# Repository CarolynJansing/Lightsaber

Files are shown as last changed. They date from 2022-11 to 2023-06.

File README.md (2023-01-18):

# Lightsaber
A lightsaber is a fictional energy sword featured in the Star Wars franchise. This project is a simulation of a lightsaber using LEDs, Sound and an Arduino microcontroller. It is based on the Gyversaber. https://www.instructables.com/Arduino-Based-Lightsaber-With-Light-and-Sound-Effe/

## Files

ArduinoCode : GyverSaber/GyverSaber/Gyversaber.ino

SD Files : GyverSaber/SDsounds

Schemes: PCB/

## Getting Started
These instructions will help you get a copy of the project up and running on your local machine for development and testing purposes.

### Prerequisites
To use this project, you will need the following:

Arduino IDE (https://www.arduino.cc/software)
•	Arduino NANO 
•	Adressable LED stripes WS2811, 12V
•	Button with LED 
•	MPU6050 
•	DF-Player
•	Batteries 18650 with Protection
•	DCDC Step-Down
•	Speaker
•	Resistors
•	Power button
•	Charging port
•	CC CV Charger for 3 cells
•	PCB-Board
•	Blade Pipe
•	PVC Pipes for hilt
•	Wire
•	3D druck
•	Soldering Supplies
I chose to use an PCB aswell you can configure it with my files on JLCPCB

### Installing
Clone the repository to your local machine: git clone https://github.com/CarolynJansing/Lightsaber.git
Open the Arduino IDE and open the Gyversaber.ino file from the cloned repository.
Connect the Arduino microcontroller to your computer using a USB cable.
Select the correct board and port in the Arduino IDE (Tools > Board and Tools > Port).
Upload the code to the Arduino microcontroller.
### Usage
The lightsaber can be controlled by the button. The buttons can be used to turn the lightsaber on and off, change the color of the lightsaber, and change the lightsaber mode.

## Built With
Arduino Nano following the Gyversaber Instructions and changed to a DFPlayer
## Author
Carolyn Jansing - CarolynJansing
+ MadGyver
License
This project is licensed under the MIT License - see the LICENSE file for details.

## Acknowledgments
The Star Wars franchise for inspiration and MadGyver.

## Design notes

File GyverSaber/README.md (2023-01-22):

# This project is based on Gyversaber
 See his inmstructions below

# GyverSaber - Arduino based multicolor sound playing lightsaber
* [Project description](#chapter-0)
* [Folders](#chapter-1)
* [Schemes](#chapter-2)
* [Components](#chapter-3)
* [Assemply and set up](#chapter-7)

## Project description
SUPER-DUPER COOL ARDUINO BASED MULTICOLOR SOUND PLAYING LIGHTSABER!
https://youtu.be/__gp2RfTMnk

## Download last release
[**Click me**](https://github.com/AlexGyver/EnglishProjects/releases/download/GyverSaber/GyverSaber.rar)

#### CAPABILITIES:
* Smooth turning on/off with lightsaber-like sound effect
* Randomly pulsing color (you can turn it off)
* Sounds:
  + MODE 1: generated hum. Frequency depends on angle velocity of blade
  + MODE 2: hum sound from SD card
    - Slow swing - long hum sound (randomly from 4 sounds)
    - Fast swing - short hum sound (randomly from 5 sounds)
* Bright white flash when hitting
* Play one of 16 hit sounds, when hit
  + Weak hit - short sound
  + Hard hit - long "bzzzghghhdh" sound
* After power on blade shows current battery level from 0 to 100 percent
* Battery safe mode:
  + Battery is drain BEFORE TURNING ON: GyverSaber will not turn on, button LED will PULSE a couple of times
  + Battery is drain AFTER TURNING ON: GyverSaber will be turned off automatically
#### CONTROL BUTTON:
* HOLD - turn on / turn off GyverSaber
* TRIPLE CLICK - change color (red - green - blue - yellow - pink - ice blue)
* QUINARY CLICK - change sound mode (hum generation - hum playing)
* Selected color and sound mode stored in EEPROM (non-volatile memory)

## Folders
- **libraries** - libraries
- **GyverSaber** - arduino sketch
- **SDsounds** - GyverSaber sound pack

## Schemes
SCHEME
SCHEME
SCHEME

## Components
* Arduino NANO https://ali.ski/jmFH9_ https://ali.ski/5OBVTQ
* Addressable LED strip. WS2811, 12V. Take **white PCB, IP30, 60 LEDs per meter**
https://ali.ski/NMjk8 https://ali.ski/zW95D
* Button with LED. **Take 5V version** https://ali.ski/Mwcxt
* MPU6050 https://ali.ski/v5KZLL https://ali.ski/uXu5vi
* Cheap MicroSD https://ali.ski/GxgI4D
* MicroSD module mini https://ali.ski/JHIePz https://ali.ski/KsPKO
* Or this https://ali.ski/WKZdDk
* Batteries 18650 with protection https://ali.ski/XBqThJ https://ali.ski/lx5do https://ali.ski/3DZON9
* DCDC Step Down https://ali.ski/Gu17D https://ali.ski/LGc7S https://ali.ski/AZ7FEd
* Amplifier https://ali.ski/w3a6s https://ali.ski/UJQHAm https://ali.ski/9chyq
* Speaker https://ali.ski/fkf3b5 https://ali.ski/f3bznw https://ali.ski/NGb4L
* Resistors KIT https://ali.ski/DsRXU https://ali.ski/0QeVi
* Power button https://ali.ski/ADn0zC
* Charging port https://ali.ski/-02oW https://ali.ski/-gRAOg
* CC CV charger for 3 cells https://ali.ski/uPeDvv https://ali.ski/QY79Lj https://ali.ski/xxHSRf
* Prototype board https://ali.ski/XTO9n

## Assembly and set up
* [Quick start with Arduino](https://learn.sparkfun.com/tutorials/installing-arduino-ide)
* Open GyverSaber.ino and tune:
  - Number of microcircuits WS2811 on LED strip (note: one WS2811 controls 3 LEDs!)
  - Turn on or turn off blade pulsation
  - Hardly recommend measure real resistance of voltage divider resistors
    + System can work without battery monitoring, just deactivate BATTERY_SAFE. **BUT IT IS NOT RECOMMENDED**
* Flash arduino
* MicroSD info:
  - Size < 4G
  - Format to FAT
  - Copy audiofiles **in the root**
  - If you want add your own sounds, convert them to .WAV:
    + 8 bit
	+ 16-32 kHz
	+ Mono
	+ Use online converters or Total Audio Converter
* Assemble schmeme
  - **WARNING!** If you are flashing **assembled scheme**, you must power up it! Arduino will not work correct with connected DCDC converter!
* Enjoy!

## GyverSaber settings
    NUM_LEDS 30         // number of microcircuits WS2811 on LED strip (note: one WS2811 controls 3 LEDs!)
    BTN_TIMEOUT 800     // button hold delay, ms
    BRIGHTNESS 255      // max LED brightness (0 - 255)

    SWING_TIMEOUT 500   // timeout between swings
    SWING_L_THR 150     // swing angle speed threshold
    SWING_THR 300       // fast swing angle speed threshold
    STRIKE_THR 150      // hit acceleration threshold
    STRIKE_S_THR 320    // hard hit acceleration threshold
    FLASH_DELAY 80      // flash time while hit

    PULSE_ALLOW 1       // blade pulsation (1 - allow, 0 - disallow)
    PULSE_AMPL 20       // pulse amplitude
    PULSE_DELAY 30      // delay between pulses

    R1 100000           // voltage divider real resistance
    R2 51000            // voltage divider real resistance
    BATTERY_SAFE 1      // battery monitoring (1 - allow, 0 - disallow)

    DEBUG 0             // debug information in Serial (1 - allow, 0 - disallow)

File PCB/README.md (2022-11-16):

Project files fro KiCad.

Created and designed by @simonmicro with :hearts: 2022

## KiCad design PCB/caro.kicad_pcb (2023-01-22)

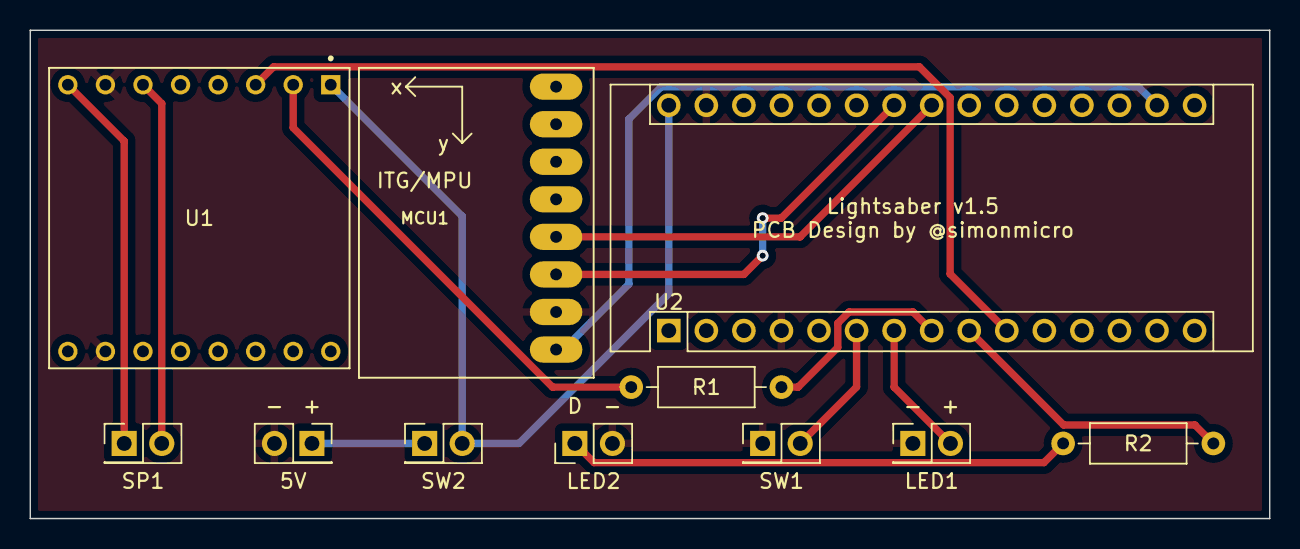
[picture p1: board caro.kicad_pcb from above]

Board: 2 copper layers, 83.8 x 33.0 mm, 11 parts (0 on the bottom side), 15 nets.

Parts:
5V: PinSocket_2x01_P2.54mm_Vertical
LED1: Control Button LED; PinHeader_2x01_P2.54mm_Vertical
LED2: WS2811; PinHeader_1x02_P2.54mm_Vertical
MCU1: GY-521
R1, R2: 1000Ohm; R_Axial_DIN0207_L6.3mm_D2.5mm_P10.16mm_Horizontal
SP1: Speaker; PinHeader_2x01_P2.54mm_Vertical
SW1: Control Button; PinHeader_2x01_P2.54mm_Vertical
SW2: Power Switch; PinHeader_2x01_P2.54mm_Vertical
U1: DFR0299; MODULE_DFR0299
U2: Arduino_Nano_v3.x; Arduino_Nano

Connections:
3.3V: MCU1.1 (VCC), U2.17 (3V3)
5V: SW2.2 (B), U1.1 (VCC), U2.30 (VIN)
+5V: 5V.1, SW2.1 (A)
A4: MCU1.4 (SDA), U2.23 (A4)
A5: MCU1.3 (SCL), U2.24 (A5)
D3: SW1.1, U2.6 (D3)
D4: LED1.2 (A), U2.7 (D4)
D5: R1.1, U2.8 (D5)
D6: R2.1, U2.9 (D6)
D7: U1.3 (TX), U2.10 (D7)
GND: 5V.2, LED1.1 (K), LED2.2 (OUTG), MCU1.2 (GND), SW1.2, U1.7 (GND), U1.10 (GND), U2.4 (GND), U2.29 (GND)
unnamed: R1.2, U1.2 (RX)
unnamed: LED2.1 (OUTR), R2.2
unnamed: SP1.1, U1.8 (SPK2)
unnamed: SP1.2, U1.6 (SPK1)

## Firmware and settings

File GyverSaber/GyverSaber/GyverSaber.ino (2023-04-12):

/*
  ARDUINO BASED MULTICOLOR SOUND PLAYING LIGHTSABER!
    HARDWARE:
      Addressable LED strip (WS2811) to get any blade color and smooth turn on effect
      DFPlaye module to play some sounds
      IMU MPU6050 (accel + gyro) to play sound matching to the swings
    CAPABILITIES:
      Smooth turning on/off with lightsaber-like sound effect
      Randomly pulsing color (you can turn it off)
      Sounds:
        MODE 1: generated hum. Frequency depends on angle velocity of blade
        MODE 2: hum sound from SD card
          Slow swing - long hum sound (randomly from 4 sounds)
          Fast swing - short hum sound (randomly from 5 sounds)
      Bright white flash when hitting
      Play one of 16 hit sounds, when hit
        Weak hit - short sound
        Hard hit - long "bzzzghghhdh" sound
      After power on blade shows current battery level from 0 to 100 percent
      Battery safe mode:
        Battery is drain BEFORE TURNING ON: GyverSaber will not turn on, button LED will PULSE a couple of times
        Battery is drain AFTER TURNING ON: GyverSaber will be turned off automatically
      CONTROL BUTTON:
        HOLD - turn on / turn off GyverSaber
        TRIPLE CLICK - change color (red - green - blue - yellow - pink - ice blue)
        QUARTER CLICK- flame blade mode inspired by Touhou Tenshi Hinanawi
        QUINARY CLICK - change sound mode (hum generation - hum playing)
        Selected color and sound mode stored in EEPROM (non-volatile memory)
*/

// ---------------------------- SETTINGS -------------------------------
#define NUM_LEDS 40         // number of microcircuits WS2811 on LED strip (note: one WS2811 controls 3 LEDs!)
#define BTN_TIMEOUT 1200    // button hold delay, ms
#define BTN_HOLD_TIME 2000  // button hold delay, ms
#define BRIGHTNESS 255      // max LED brightness (0 - 255)

#define SWING_TIMEOUT 500  // timeout between swings
#define SWING_L_THR 150    // swing angle speed threshold
#define SWING_THR 300      // fast swing angle speed threshold
#define STRIKE_THR 150     // hit acceleration threshold
#define STRIKE_S_THR 320   // hard hit acceleration threshold
#define FLASH_DELAY 80     // flash time while hit

#define PULSE_ALLOW 1   // blade pulsation (1 - allow, 0 - disallow)
#define PULSE_AMPL 20   // pulse amplitude
#define PULSE_DELAY 30  // delay between pulses

#define BATTERY_SAFE 0  // battery monitoring (1 - allow, 0 - disallow)

#define DEBUG 1  // debug information in Serial (1 - allow, 0 - disallow)
// ---------------------------- SETTINGS -------------------------------

#define LED_PIN 2
#define BTN 13
#define BTN_LED 0 // -1 -> disable, 4 original
#define SD_ChipSelectPin 10

// -------------------------- LIBS ---------------------------
#include <avr/pgmspace.h>  // PROGMEM library
// #include <TMRpcm.h>  // audio from SD library
#include "Wire.h"
#include "I2Cdev.h"
#include "MPU6050.h"
#include <toneAC.h>   // hum generation library
#include "FastLED.h"  // addressable LED library
#include <EEPROM.h>
#include "Arduino.h"
#include "SoftwareSerial.h"
#include "DFRobotDFPlayerMini.h"

// TMRpcm tmrpcm;
MPU6050 accelgyro;
SoftwareSerial mySoftwareSerial(14, 12);  // RX, TX

DFRobotDFPlayerMini myDFPlayer;
void printDetail(uint8_t type, int value);

CRGB leds[NUM_LEDS];

// -------------------------- LIBS ---------------------------

// ------------------------------ VARIABLES ---------------------------------

int16_t ax, ay, az;
int16_t gx, gy, gz;
unsigned long ACC, GYR, COMPL;
int gyroX, gyroY, gyroZ, accelX, accelY, accelZ, freq, freq_f = 20;
float k = 0.2;
unsigned long humTimer = -9000, mpuTimer, nowTimer;
int stopTimer;
boolean bzzz_flag, ls_chg_state, ls_state;
unsigned long PULSE_timer, swing_timer, swing_timeout, battery_timer, bzzTimer;
byte nowNumber;
byte LEDcolor;  // 0 - red, 1 - green, 2 - blue, 3 - pink, 4 - yellow, 5 - ice blue
byte nowColor, red, green, blue, redOffset, greenOffset, blueOffset;
boolean eeprom_flag, swing_flag, swing_allow, strike_flag, HUMmode;
float voltage;
int PULSEOffset;
boolean tenshiMode;
// ------------------------------ VARIABLES ---------------------------------

// --------------------------------- SOUNDS ----------------------------------

int strike_time[8] = { 779, 563, 687, 702, 673, 661, 666, 635 };

int strike_s_time[8] = { 270, 167, 186, 250, 252, 255, 250, 238 };

int swing_time[8] = { 389, 372, 360, 366, 337 };

int swing_time_L[8] = { 636, 441, 772, 702 };

int BUFFER[10];
// --------------------------------- SOUNDS ---------------------------------

void setup() {
  pinMode(13, INPUT_PULLUP);
  Serial.begin(115200);

  FastLED.addLeds<WS2811, LED_PIN, BRG>(leds, NUM_LEDS).setCorrection(TypicalLEDStrip);
  FastLED.setBrightness(255);  // ~40% of LED strip brightness
  setAll(0, 0, 0);             // and turn it off

  Wire.begin();
  // Audio SetUp
  mySoftwareSerial.begin(9600);
  Serial.println(F("DFRobot DFPlayer Mini Demo"));
  Serial.println(F("Initializing DFPlayer ... (May take 3~5 seconds)"));

  if (!myDFPlayer.begin(mySoftwareSerial)) {  // Use softwareSerial to communicate with mp3.
    Serial.println(F("Unable to begin:"));
    Serial.println(F("1.Please recheck the connection!"));
    Serial.println(F("2.Please insert the SD card!"));
  }

  Serial.println(F("DFPlayer Mini online."));

  //----Set volume----
  myDFPlayer.volume(20);  // Set volume value (0~30).

  //----Set different EQ----
  myDFPlayer.EQ(DFPLAYER_EQ_NORMAL);
  myDFPlayer.outputDevice(DFPLAYER_DEVICE_SD);

  // ---- PIN-Settings ----
  pinMode(BTN, INPUT_PULLUP);
  if (BTN_LED > 0)
    pinMode(BTN_LED, OUTPUT);
    
  if (BTN_LED > 0)
    digitalWrite(BTN_LED, 1);
  //---- PIN-Settings ----

  randomSeed(analogRead(2));  // starting point for random generator

  //IMU initialization
  accelgyro.initialize();
  accelgyro.setFullScaleAccelRange(MPU6050_ACCEL_FS_16);
  accelgyro.setFullScaleGyroRange(MPU6050_GYRO_FS_250);
  if (DEBUG)
  {
    if (accelgyro.testConnection())
      Serial.println(F("MPU6050 OK"));
    else
      Serial.println(F("MPU6050 fail"));
  }

  // SD initialization was replaced by DFPlayer
  /* tmrpcm.speakerPin = 9;
   tmrpcm.setVolume(5);
   tmrpcm.quality(1);
   if (DEBUG) {
     if (SD.begin(8)) Serial.println(F("SD OK"));
     else Serial.println(F("SD fail"));
   } else {
     SD.begin(8);
   }*/

  if ((EEPROM.read(0) >= 0) && (EEPROM.read(0) <= 5)) {  // check first start
    nowColor = EEPROM.read(0);                           // remember color
    HUMmode = EEPROM.read(1);                            // remember mode
  } else {                                               // first start
    EEPROM.write(0, 0);                                  // set default
    EEPROM.write(1, 0);                                  // set default
    nowColor = 0;                                        // set default
  }

  setColor(nowColor);
  // byte capacity = voltage_measure();                        // get battery level
  // capacity = map(capacity, 100, 0, (NUM_LEDS / 2 - 1), 1);  // convert into blade lenght
  if (DEBUG) {
    Serial.print(F("Battery: "));
    // Serial.println(capacity);
  }

  // for (char i = 0; i <= capacity; i++) {  // show battery level
  //   setPixel(i, red, green, blue);
  //   setPixel((NUM_LEDS - 1 - i), red, green, blue);
  //   FastLED.show();
  //   delay(25);
  // }
  delay(1000);  // 1 second to show battery level
  setAll(0, 0, 0);
  FastLED.setBrightness(BRIGHTNESS);  // set bright
}

// --- MAIN LOOP---
void loop() {
  if (!tenshiMode) {
    randomPULSE();
    getFreq();
    on_off_sound();
    btnTick();
    strikeTick();
    swingTick();
  } else {
    on_off_sound();
    btnTick();
    Fire2012();      // run simulation frame
    FastLED.show();  // display this frame
    FastLED.delay(1000 / 60);
  }
  // batteryTick();
}
// --- MAIN LOOP---

void btnTick() {
  // BTN_TIMEOUT, BTN_HOLD_TIMEOUT
  static unsigned long lastClickStartedOn = 0;
  static unsigned char clickCounter = 0;
  static bool lastClickState = false;
  static bool isClickHeld = false;
  bool currentClickState = digitalRead(BTN);
  if (currentClickState and !lastClickState) {
    lastClickState = true;
    clickCounter++;
    lastClickStartedOn = millis();
    if (DEBUG) {
      Serial.print(F("BTN PRESS (STATE "));
      Serial.print(currentClickState);
      Serial.print(F("; COUNT "));
      Serial.print(clickCounter);
      Serial.println(F(")"));
    }
  } else if (!currentClickState and lastClickState) {
    lastClickState = false;
    isClickHeld = false;
  }

  // ...if button is held
  if (currentClickState and clickCounter == 1 and (millis() - lastClickStartedOn > BTN_HOLD_TIME) and !isClickHeld) {
    if (DEBUG)
      Serial.println(F("BTN HELD -> TRIGGER"));
    ls_chg_state = 1;  // flag to change saber state (on/off)
    isClickHeld = true;
  }

  // Only process the click if it is being held long enough
  if (!currentClickState and clickCounter > 0 and (millis() - lastClickStartedOn > BTN_TIMEOUT) and !isClickHeld) {
    if (DEBUG)
      Serial.println(F("BTN CLICK PROCESSING..."));
    if (ls_state) {
      if (clickCounter == 3) {
        tenshiMode = false;  // 3 press count
        nowColor++;          // change color
        if (nowColor >= 6)
          nowColor = 0;
        setColor(nowColor);
        setAll(red, green, blue);
        eeprom_flag = 1;
      }
      if (clickCounter == 4) {
        tenshiMode = true;
        myDFPlayer.playFolder(1, 33);
      }
      if (clickCounter == 5) {  // 5 press count
        HUMmode = !HUMmode;
        if (HUMmode) {
          if (!tenshiMode) { myDFPlayer.loop(1); }
        } else {
        }
        eeprom_flag = 1;
      }
    }

    if (DEBUG)
      Serial.println(F("BTN TIMEOUT -> COUNTER RESET"));
    clickCounter = 0;
  }
}

void on_off_sound() {
  if (ls_chg_state) {  // if change flag
    if (!ls_state) {   // if GyverSaber is turned off
      // if (voltage_measure() > 10 || !BATTERY_SAFE) {
      //   if (DEBUG)
      //     Serial.println(F("SABER ON"));
      //   myDFPlayer.playFolder(1, 3);  // Play On sound
      //   delay(200);
      //   light_up();
      //   delay(200);
      //   bzzz_flag = 1;
      //   ls_state = true;  // remember that turned on
      //   if (HUMmode) {
      //     if (!tenshiMode) { myDFPlayer.loop(1); }
      //   } else {
      //   }
      // } else 
      // {
        if (DEBUG)
          Serial.println(F("LOW VOLTAGE!"));
        for (int i = 0; i < 5; i++) {
          if (BTN_LED > 0)
            digitalWrite(BTN_LED, 0);
          delay(400);
          if (BTN_LED > 0)
            digitalWrite(BTN_LED, 1);
          delay(400);
        }
      // }
    } else {  // if GyverSaber is turned on
      tenshiMode = false;
      bzzz_flag = 0;
      myDFPlayer.playFolder(1, 3);  // play off sound
      delay(300);
      light_down();
      myDFPlayer.disableLoop();
      delay(300);
      if (DEBUG)
        Serial.println(F("SABER OFF"));
      ls_state = false;
      if (eeprom_flag) {
        eeprom_flag = 0;
        EEPROM.write(0, nowColor);  // write color in EEPROM
        EEPROM.write(1, HUMmode);   // write mode in EEPROM
      }
    }
    ls_chg_state = 0;
  }

  if (((millis() - humTimer) > 9000) && bzzz_flag && HUMmode) {
    if (!tenshiMode) { myDFPlayer.loop(1); }
    humTimer = millis();
    swing_flag = 1;
    strike_flag = 0;
  }
  long delta = millis() - bzzTimer;
  if ((delta > 3) && bzzz_flag && !HUMmode) {
    if (strike_flag) {
      // tmrpcm.disable();
      strike_flag = 0;
    }
    toneAC(freq_f, 1);
    bzzTimer = millis();
  }
}

void randomPULSE() {

  if (PULSE_ALLOW && ls_state && (millis() - PULSE_timer > PULSE_DELAY)) {
    PULSE_timer = millis();
    PULSEOffset = PULSEOffset * k + random(-PULSE_AMPL, PULSE_AMPL) * (1 - k);
    if (nowColor == 0)
      PULSEOffset = constrain(PULSEOffset, -15, 5);
    redOffset = constrain(red + PULSEOffset, 0, 255);
    greenOffset = constrain(green + PULSEOffset, 0, 255);
    blueOffset = constrain(blue + PULSEOffset, 0, 255);
    setAll(redOffset, greenOffset, blueOffset);
  }
}

void strikeTick() {
  if ((ACC > STRIKE_THR) && (ACC < STRIKE_S_THR)) {
    if (!HUMmode)
      noToneAC();
    nowNumber = random(8);
    // read the name of the sound from PROGMEM
    // strcpy_P(BUFFER, (int*)pgm_read_word(&(strikes_short[nowNumber])));
    Serial.println("Strike play");
    myDFPlayer.playFolder(1, random(12, 20));
    hit_flash();
    if (!HUMmode)
      bzzTimer = millis() + strike_s_time[nowNumber] - FLASH_DELAY;
    else
      humTimer = millis() - 9000 + strike_s_time[nowNumber] - FLASH_DELAY;
    strike_flag = 1;
  }
  if (ACC >= STRIKE_S_THR) {
    if (!HUMmode)
      noToneAC();
    nowNumber = random(8);
    // read the name of the sound from PROGMEM
    // strcpy_P(BUFFER, (char*)pgm_read_word(&(strikes[nowNumber])));
    Serial.println("Strike play S");
    myDFPlayer.playFolder(1, random(4, 12));
    hit_flash();
    if (!HUMmode)
      bzzTimer = millis() + strike_time[nowNumber] - FLASH_DELAY;
    else
      humTimer = millis() - 9000 + strike_time[nowNumber] - FLASH_DELAY;
    strike_flag = 1;
  }
}

void swingTick() {
  if (GYR > 80 && (millis() - swing_timeout > 100) && HUMmode) {
    Serial.println("SWINGIN");
    swing_timeout = millis();
    if (((millis() - swing_timer) > SWING_TIMEOUT) && swing_flag && !strike_flag) {
      if (GYR >= SWING_THR) {
        Serial.println("SWING NORMAL");
        nowNumber = random(5);
        // read the name of the sound from PROGMEM
        // strcpy_P(BUFFER, (char*)pgm_read_word(&(swings[nowNumber])));
        myDFPlayer.playFolder(1, random(24, 29));
        humTimer = millis() - 9000 + swing_time[nowNumber];
        swing_flag = 0;
        swing_timer = millis();
        swing_allow = 0;
      }
      if ((GYR > SWING_L_THR) && (GYR < SWING_THR)) {
        Serial.println("SWING LARGE");

        nowNumber = random(5);
        // read the name of the sound from PROGMEM
        // strcpy_P(BUFFER, (char*)pgm_read_word(&(swings_L[nowNumber])));
        myDFPlayer.playFolder(1, random(20, 24));
        humTimer = millis() - 9000 + swing_time_L[nowNumber];
        swing_flag = 0;
        swing_timer = millis();
        swing_allow = 0;
      }
    }
  }
}

void getFreq() {
  if (ls_state) {  // if GyverSaber is on
    if (millis() - mpuTimer > 500) {
      accelgyro.getMotion6(&ax, &ay, &az, &gx, &gy, &gz);

      // find absolute and divide on 100
      gyroX = abs(gx / 100);
      gyroY = abs(gy / 100);
      gyroZ = abs(gz / 100);
      accelX = abs(ax / 100);
      accelY = abs(ay / 100);
      accelZ = abs(az / 100);

      // vector sum
      ACC = sq((long)accelX) + sq((long)accelY) + sq((long)accelZ);
      ACC = sqrt(ACC);
      GYR = sq((long)gyroX) + sq((long)gyroY) + sq((long)gyroZ);
      GYR = sqrt((long)GYR);
      COMPL = ACC + GYR;

      // debugging the IMU
        //  Serial.print("$");
        //  Serial.print(gyroX);
        //  Serial.print(" ");
        //  Serial.print(gyroY);
        //  Serial.print(" ");
        //  Serial.print(gyroZ);
        //  Serial.println(";");
        //  Serial.println(GYR);

      freq = (long)COMPL * COMPL / 1500;  // parabolic tone change
      freq = constrain(freq, 18, 300);
      freq_f = freq * k + freq_f * (1 - k);  // smooth filter
      mpuTimer = micros();
    }
  }
}

void setPixel(int Pixel, byte red, byte green, byte blue) {
  leds[Pixel].r = red;
  leds[Pixel].g = green;
  leds[Pixel].b = blue;
}

void setAll(byte red, byte green, byte blue) {
  for (int i = 0; i < NUM_LEDS; i++) {
    setPixel(i, red, green, blue);
  }
  FastLED.show();
}

void light_up() {
  for (char i = 0; i <= (NUM_LEDS / 2 - 1); i++) {
    setPixel(i, red, green, blue);
    setPixel((NUM_LEDS - 1 - i), red, green, blue);
    FastLED.show();
    delay(25);
  }
}

void light_down() {
  for (char i = (NUM_LEDS / 2 - 1); i >= 0; i--) {
    setPixel(i, 0, 0, 0);
    setPixel((NUM_LEDS - 1 - i), 0, 0, 0);
    FastLED.show();
    delay(25);
  }
}

void hit_flash() {
  setAll(255, 255, 255);
  delay(FLASH_DELAY);
  setAll(red, blue, green);
}

void setColor(byte color) {
  switch (color) {
    // 0 - red, 1 - green, 2 - blue, 3 - pink, 4 - yellow, 5 - ice blue
    case 0:
      red = 255;
      green = 0;
      blue = 0;
      break;
    case 1:
      red = 0;
      green = 0;
      blue = 255;
      break;
    case 2:
      red = 0;
      green = 255;
      blue = 0;
      break;
    case 3:
      red = 255;
      green = 0;
      blue = 255;
      break;
    case 4:
      red = 255;
      green = 255;
      blue = 0;
      break;
    case 5:
      red = 0;
      green = 255;
      blue = 255;
      break;
  }
}

void batteryTick() {
  if (millis() - battery_timer > 30000 && ls_state && BATTERY_SAFE) {
    // if (voltage_measure() < 15) {
    //   ls_chg_state = 1;
    // }
    battery_timer = millis();
  }
}

// byte voltage_measure() {
//   int R1 = 51000;
//   int R2 = 100000;
//   voltage = 0;
//   for (int i = 0; i < 10; i++) {
//     voltage += (float)0.5* 5 / 1023 * (R1 + R2) / R2;
//   }
//   voltage = voltage / 10;
//   int volts = voltage / 3 * 100;  // 3 cells!!!
//   if (volts > 387)
//     return map(volts, 420, 387, 100, 77);
//   else if ((volts <= 387) && (volts > 375))
//     return map(volts, 387, 375, 77, 54);
//   else if ((volts <= 375) && (volts > 368))
//     return map(volts, 375, 368, 54, 31);
//   else if ((volts <= 368) && (volts > 340))
//     return map(volts, 368, 340, 31, 8);
//   else if (volts <= 340)
//     return map(volts, 340, 260, 8, 0);
//  }

// COOLING: How much does the air cool as it rises?
// Less cooling = taller flames.  More cooling = shorter flames.
// Default 50, suggested range 20-100
#define COOLING 55

// SPARKING: What chance (out of 255) is there that a new spark will be lit?
// Higher chance = more roaring fire.  Lower chance = more flickery fire.
// Default 120, suggested range 50-200.
#define SPARKING 120


void Fire2012() {

  bool gReverseDirection = false;
  // Array of temperature readings at each simulation cell
  static uint8_t heat[NUM_LEDS];

  // Step 1.  Cool down every cell a little
  for (int i = 0; i < NUM_LEDS; i++) {
    heat[i] = qsub8(heat[i], random8(0, ((COOLING * 10) / NUM_LEDS) + 2));
  }

  // Step 2.  Heat from each cell drifts 'up' and diffuses a little
  for (int k = NUM_LEDS - 1; k >= 2; k--) {
    heat[k] = (heat[k - 1] + heat[k - 2] + heat[k - 2]) / 3;
  }

  // Step 3.  Randomly ignite new 'sparks' of heat near the bottom
  if (random8() < SPARKING) {
    int y = random8(7);
    heat[y] = qadd8(heat[y], random8(160, 255));
  }

  // Step 4.  Map from heat cells to LED colors
  for (int j = 0; j < NUM_LEDS; j++) {
    CRGB color = HeatColor(heat[j]);
    int pixelnumber;
    if (gReverseDirection) {
      pixelnumber = (NUM_LEDS - 1) - j;
    } else {
      pixelnumber = j;
    }
    leds[pixelnumber] = color;
  }
}

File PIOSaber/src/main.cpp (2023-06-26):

// Other files
#include "leds.hpp"
#include "sounds.hpp"
#include "button.hpp"
#include "battery.hpp"
#include "accelerometer.hpp"
#include "wlan.hpp"
#include "mqtt.hpp"
#include <config.hpp>

#include <EEPROM.h>



// Variables shared with other files
LightSaberEnabled lightSaberEnabled;
bool storeColorAndHumToEEPROM, isLightsaberHumming;
bool tenshiModeEnabled;

// Variables for main.cpp
float k = 0.2;
unsigned long soundSwingStartedTime, soundSwingLastTick;

byte soundIndex;
const int soundTimeStrike[8] = { 779, 563, 687, 702, 673, 661, 666, 635 };
const int soundTimeStrikes[8] = { 270, 167, 186, 250, 252, 255, 250, 238 };
const int soundTimeSwing[8] = { 389, 372, 360, 366, 337 };
const int soundTimeSwingLong[8] = { 636, 441, 772, 702 };

void strikeTick() {
  if ((ACC > STRIKE_THR) && (ACC < STRIKE_S_THR)) {
    soundIndex = random(8);
    Serial.println("Strike play");
    ////new_mqtt_event(MQTT_EVENT::STRIKE);
    dfPlayer.playFolder(1, random(12, 20));
    hit_flash();
    if (!isLightsaberHumming)
      soundBzzStartedTime = millis() + soundTimeStrikes[soundIndex] - FLASH_DELAY;
    else
      soundHumStartedTime = millis() - 9000 + soundTimeStrikes[soundIndex] - FLASH_DELAY;
    isLightsaberStriking = true;
  }
  if (ACC >= STRIKE_S_THR) {
    soundIndex = random(8);
    Serial.println("Strike play S");
    //new_mqtt_event(MQTT_EVENT::STRIKE_S);
    dfPlayer.playFolder(1, random(4, 12));
    hit_flash();
    if (!isLightsaberHumming)
      soundBzzStartedTime = millis() + soundTimeStrike[soundIndex] - FLASH_DELAY;
    else
      soundHumStartedTime = millis() - 9000 + soundTimeStrike[soundIndex] - FLASH_DELAY;
    isLightsaberStriking = true;
  }
}

void swingTick() {
  if (GYR > 80 && (millis() - soundSwingLastTick > 100) && isLightsaberHumming) {
    Serial.println("SWINGIN");
    soundSwingLastTick = millis();
    if (((millis() - soundSwingStartedTime) > SWING_TIMEOUT) && isLightsaberSwinging && !isLightsaberStriking) {
      if (GYR >= SWING_THR) {
        Serial.println("SWING NORMAL");
        //new_mqtt_event(MQTT_EVENT::SWING_NORMAL);
        soundIndex = random(5);
        dfPlayer.playFolder(1, random(24, 29));
        soundHumStartedTime = millis() - 9000 + soundTimeSwing[soundIndex];
        isLightsaberSwinging = false;
        soundSwingStartedTime = millis();
      }
      if ((GYR > SWING_L_THR) && (GYR < SWING_THR)) {
        Serial.println("SWING LARGE");
        //new_mqtt_event(MQTT_EVENT::SWING_LARGE);
        soundIndex = random(5);
        dfPlayer.playFolder(1, random(20, 24));
        soundHumStartedTime = millis() - 9000 + soundTimeSwingLong[soundIndex];
        isLightsaberSwinging = false;
        soundSwingStartedTime = millis();
      }
    }
  }
}

void setup() {
  Serial.begin(115200);
  FastLED.addLeds<WS2811, LED_PIN, BRG>(leds, NUM_LEDS).setCorrection(TypicalLEDStrip);
  FastLED.setBrightness(255);  // ~40% of LED strip brightness
  setAll({0, 0, 0});             // and turn it off
  //initWiFi();
    // Audio SetUp
  dfPlayerSerial.begin(9600);
  Serial.println(F("DFRobot DFPlayer Mini Demo"));
  Serial.println(F("Initializing DFPlayer ... (May take 3~5 seconds)"));

  if (!dfPlayer.begin(dfPlayerSerial)) {  // Use softwareSerial to communicate with mp3.
    Serial.println(F("Unable to begin:"));
    Serial.println(F("1.Please recheck the connection!"));
    Serial.println(F("2.Please insert the SD card!"));
  }
  Serial.println(F("DFPlayer Mini online."));

  //----Set volume----
  dfPlayer.volume(20);  // Set volume value (0~30).

  //----Set different EQ----
  dfPlayer.EQ(DFPLAYER_EQ_NORMAL);
  dfPlayer.outputDevice(DFPLAYER_DEVICE_SD);

  // ---- PIN-Settings ----
  pinMode(BTN, INPUT_PULLUP); // to check if button is pressed (shorts to ground)
  if (BTN_LED > 0)
    pinMode(BTN_LED, OUTPUT);
    
  if (BTN_LED > 0)
    digitalWrite(BTN_LED, 1);
  //---- PIN-Settings ----

  randomSeed(analogRead(2));  // starting point for random generator

  // join I2C bus (I2Cdev library doesn't do this automatically) -> preparation for IMU
  #if I2CDEV_IMPLEMENTATION == I2CDEV_ARDUINO_WIRE
    Wire.begin();
  #elif I2CDEV_IMPLEMENTATION == I2CDEV_BUILTIN_FASTWIRE
    Fastwire::setup(400, true);
  #endif

  // IMU initialization
  accelerometer.initialize();
  if (accelerometer.testConnection())
    Serial.println(F("MPU6050 OK"));
  else
    Serial.println(F("MPU6050 fail (try hard-resetting the lightsaber); proceeding anyway..."));
  accelerometer.setFullScaleAccelRange(MPU6050_ACCEL_FS_16);
  accelerometer.setFullScaleGyroRange(MPU6050_GYRO_FS_250);

  // Read last state from EEPROM
  if ((EEPROM.read(0) >= 0) && (EEPROM.read(0) <= 5)) {
    nowColor = EEPROM.read(0);
    isLightsaberHumming = EEPROM.read(1);
  } else {
    EEPROM.write(0, 0);
    EEPROM.write(1, 0);
    nowColor = 0;
  }

  setColor(nowColor);
  // byte capacity = voltage_measure();                        // get battery level
  // capacity = map(capacity, 100, 0, (NUM_LEDS / 2 - 1), 1);  // convert into blade lenght
  if (DEBUG) {
    Serial.print(F("Battery: "));
    // Serial.println(capacity);
  }

  // for (char i = 0; i <= capacity; i++) {  // show battery level
  //   setPixel(i, {red, green, blue});
  //   setPixel((NUM_LEDS - 1 - i), {red, green, blue});
  //   FastLED.show();
  //   delay(25);
  // }
  // delay(1000);  // 1 second to show battery level
  setAll({0, 0, 0});
  FastLED.setBrightness(BRIGHTNESS);  // set bright
}

void loop() {
  if (!tenshiModeEnabled) {
    randomPULSE(lightSaberEnabled, k);
    getFreq(lightSaberEnabled, k);
    on_off_sound(lightSaberEnabled, tenshiModeEnabled, storeColorAndHumToEEPROM, isLightsaberHumming, nowColor);
    btnTick(lightSaberEnabled, tenshiModeEnabled, isLightsaberHumming, nowColor, storeColorAndHumToEEPROM);
    strikeTick();
    swingTick();
  } else {
    on_off_sound(lightSaberEnabled, tenshiModeEnabled, storeColorAndHumToEEPROM, isLightsaberHumming, nowColor);
    btnTick(lightSaberEnabled, tenshiModeEnabled, isLightsaberHumming, nowColor, storeColorAndHumToEEPROM);
    Fire2012(); // run simulation frame
    FastLED.show(); // display this frame
    FastLED.delay(1000 / 60);
  }
    //connected();

  batteryTick(lightSaberEnabled);
}

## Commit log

2022-11-13 Deleted other projects
    [GyverGun.fzz, RX.fzz, TX.fzz]
2022-11-15 fix btn tick function
    [GyverSaber.ino]
2022-11-16 Added KiCad files
    [caro.kicad_pcb, caro.kicad_sch]
2022-11-26 Corrected inverted LED pins
    [caro.kicad_pcb, caro.kicad_sch]
2022-11-27 Bump to v1.1
    [caro.kicad_pcb, caro.kicad_sch]
2022-11-27 Updated annotations Added missing control LED Reduced resistor sizes
    [caro.kicad_pcb, caro.kicad_sch]
2022-11-27 Revision v1.3 Increased HIGH_PWR width to 2mm
    [caro.kicad_pcb]
2022-11-27 Revision v1.4 Swapped MCU and SDCard
    [caro.kicad_pcb, caro.kicad_sch]
2022-11-27 Moved resistor to increase distance to HIGH_PWR tracks
    [caro.kicad_pcb]
2022-11-27 Corrected worng annotation
    [caro.kicad_pcb, caro.kicad_sch]
2023-01-22 Revision udate to v1.5 Swapped WS2812b to WS2811
    [caro.kicad_pcb, caro.kicad_sch]
2023-06-14 fix wifi function test
    [main.cpp]
